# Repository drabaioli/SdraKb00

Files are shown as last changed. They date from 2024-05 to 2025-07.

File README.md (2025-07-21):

# SdraKb00

12 keys hot-swap macropad with rotary encoder.

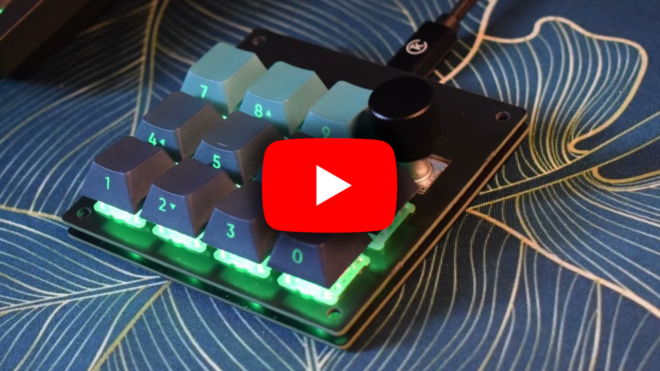
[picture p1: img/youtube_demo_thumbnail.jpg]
Watch the video (https://www.youtube.com/watch?v=uPEhIp7Z-5M)


## Assembled images

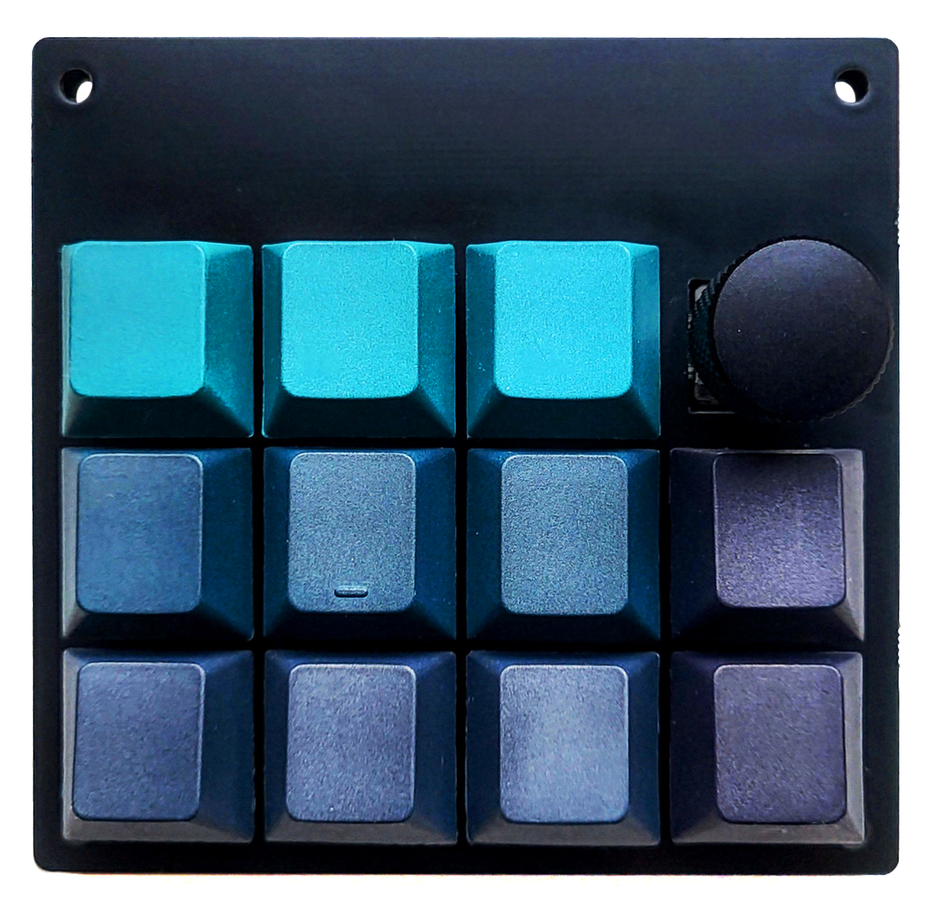
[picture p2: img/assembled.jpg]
assembled

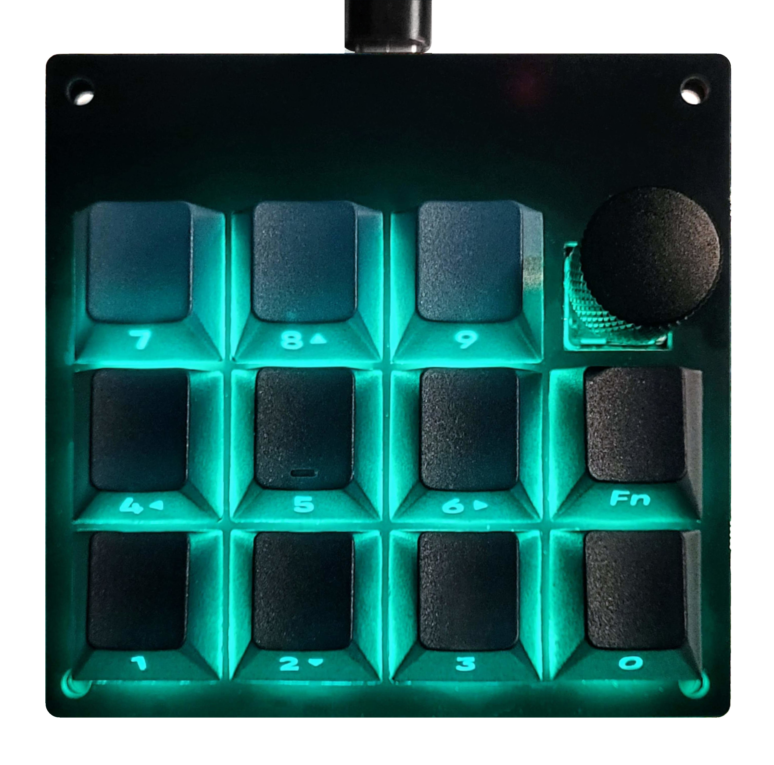
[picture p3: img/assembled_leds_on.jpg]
assembled_leds_on


## Features

- 11 hot-swap keys
- Rotary encoder with push button
- AtMega32U4 MCU
- Per-key RGB led for backlighting
- USB-C connector
- On PCB SPI header
- MCU reset button
- Switch mounting plate
- Power LED indicator

## Keyboard Layout Editor link

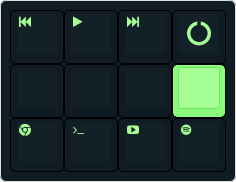
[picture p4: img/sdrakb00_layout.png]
layout
[](http://www.keyboard-layout-editor.com/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'fa%20fa-fast-backward'%3E%3C%2F%2Fi%3E&=%3Ci%20class%2F='fa%20fa-play'%3E%3C%2F%2Fi%3E&=%3Ci%20class%2F='fa%20fa-fast-forward'%3E%3C%2F%2Fi%3E&_a:7&f:9%3B&=%3Ci%20class%2F='fa%20fa-circle-o-notch'%3E%3C%2F%2Fi%3E%3B&@_f:3%3B&=&=&=&_c=%2388FB7A&t=%23101C24%3B&=%3B&@_c=%23101C24&t=%2388FB7A&a:4%3B&=%3Ci%20class%2F='fa%20fa-chrome'%3E%3C%2F%2Fi%3E&=%3Ci%20class%2F='fa%20fa-terminal'%3E%3C%2F%2Fi%3E&=%3Ci%20class%2F='fa%20fa-youtube-play'%3E%3C%2F%2Fi%3E&=%3Ci%20class%2F='fa%20fa-spotify'%3E%3C%2F%2Fi%3E)

## Schematic

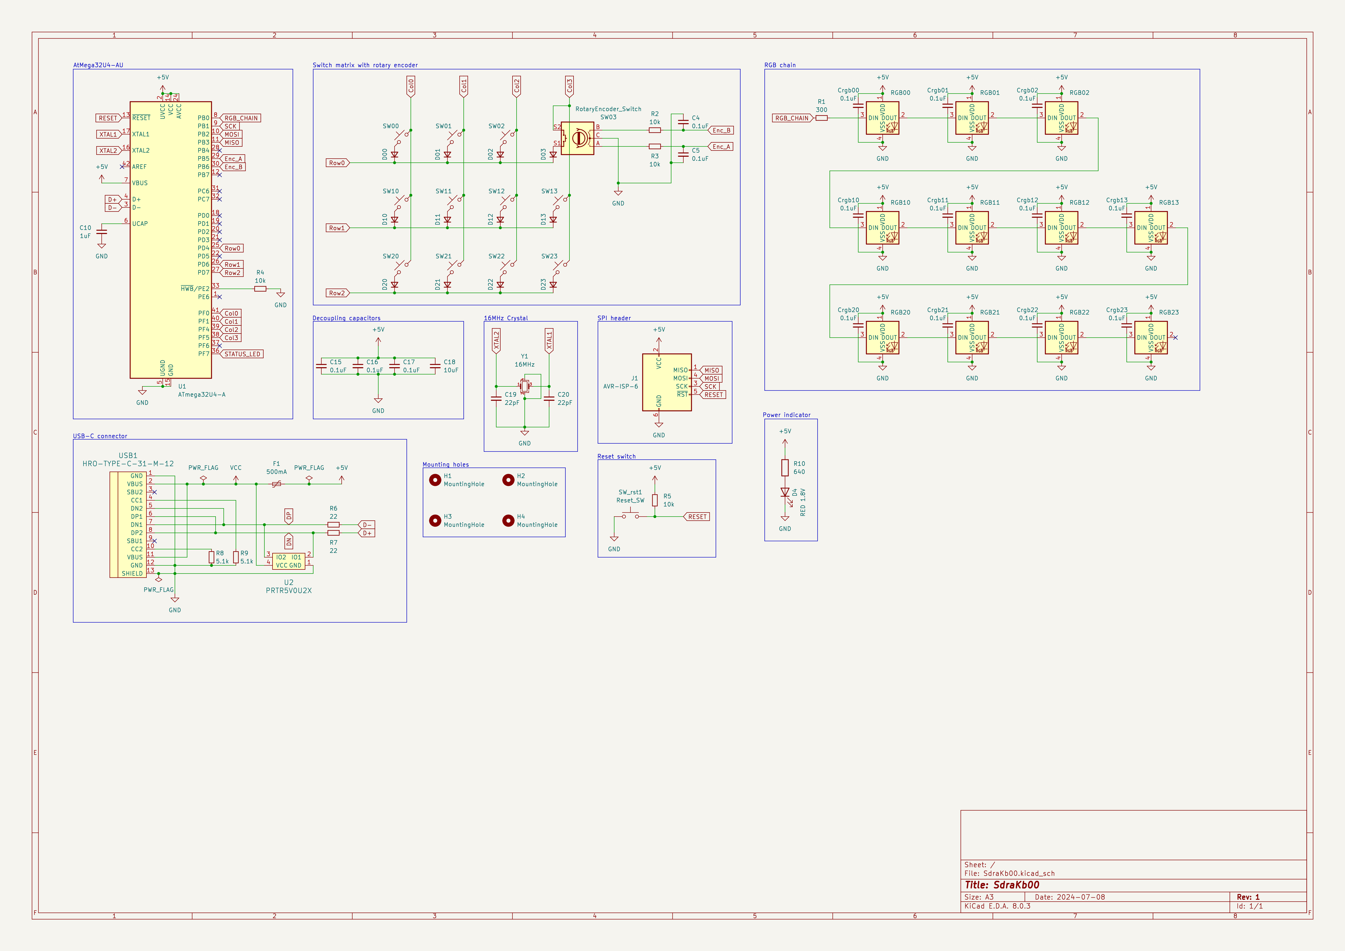
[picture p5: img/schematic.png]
schematic

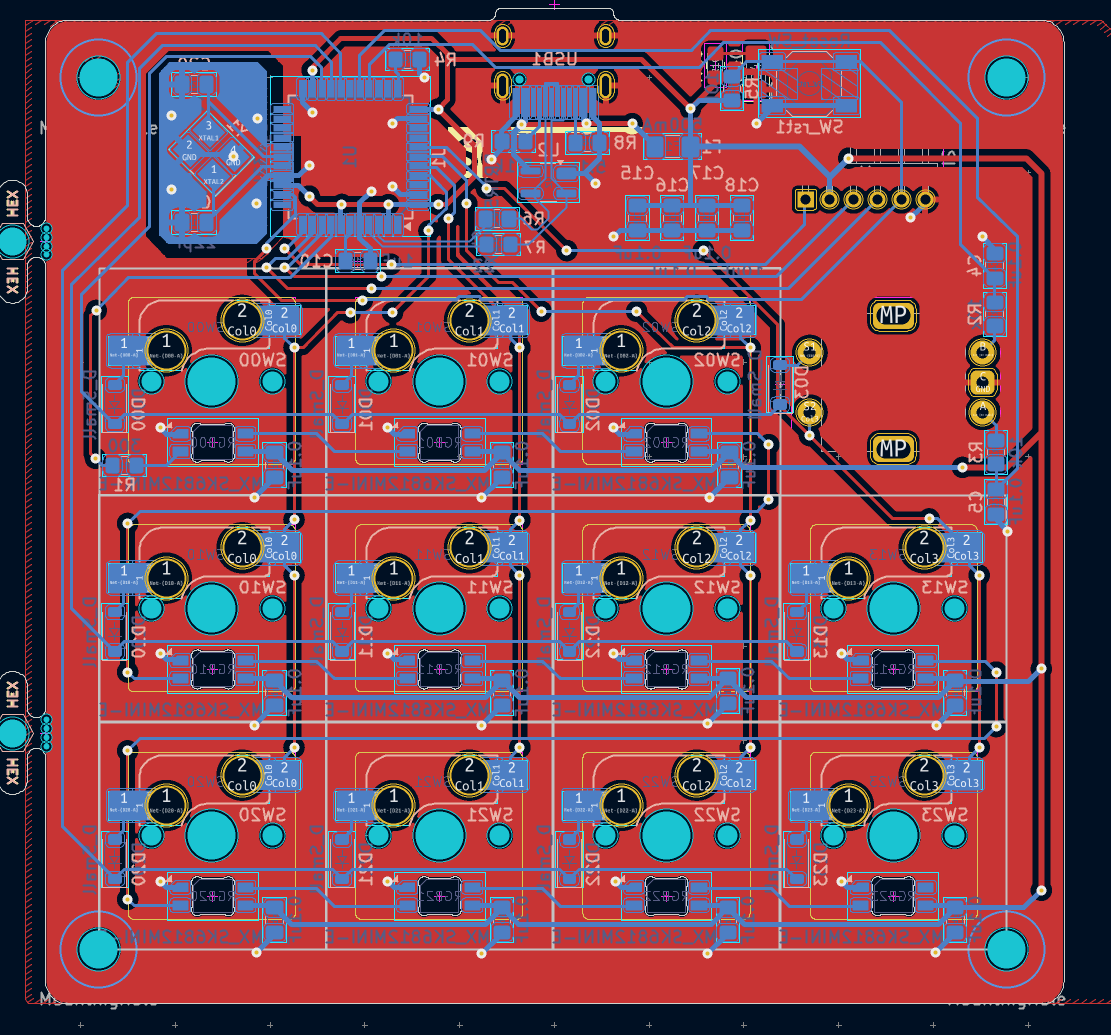
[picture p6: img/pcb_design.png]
pcb_design


## PCB

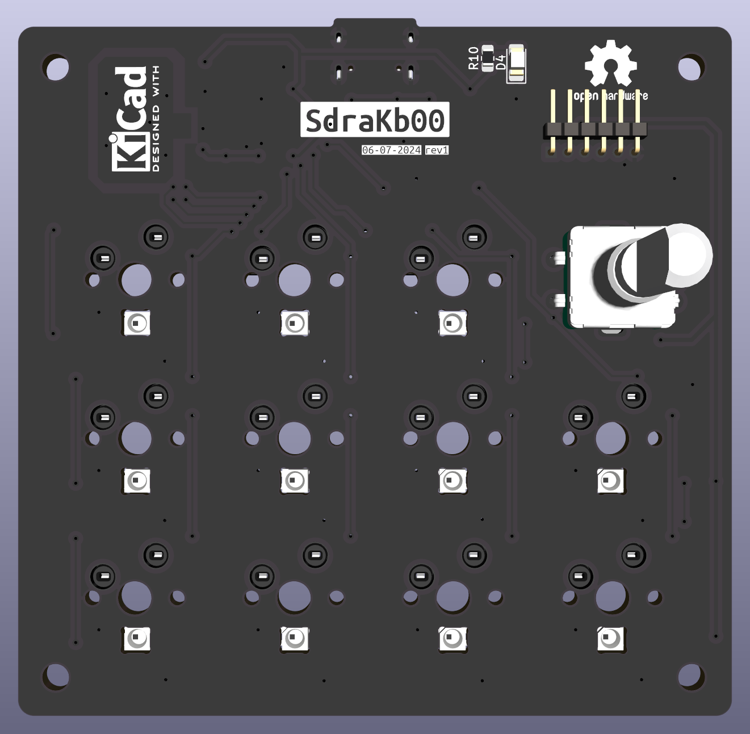
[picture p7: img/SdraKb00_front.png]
pcb_front

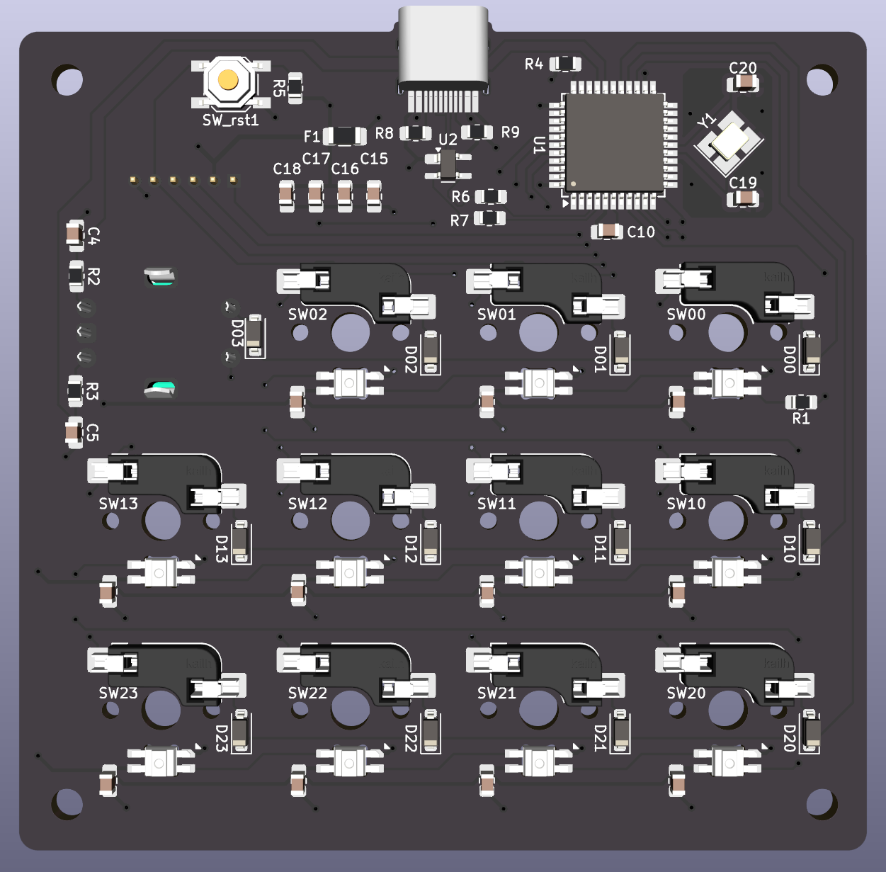
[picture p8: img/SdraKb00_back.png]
pcb_back


## Switch plate

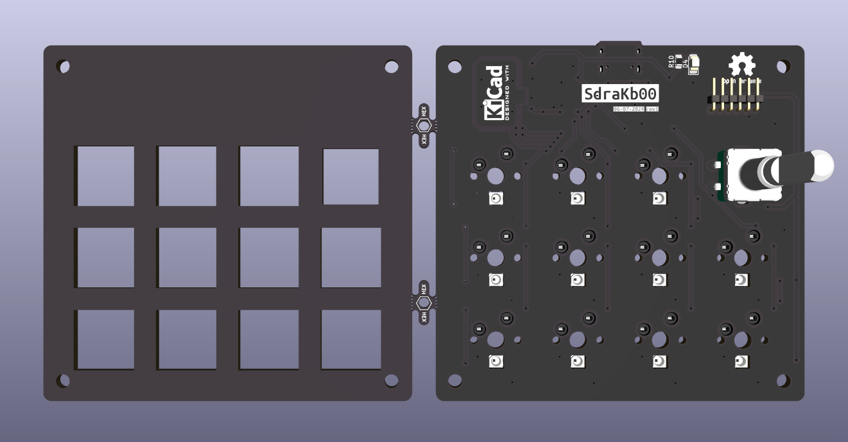
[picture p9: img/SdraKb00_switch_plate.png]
switch_plate


## Production files

The [production/](production/) folder contains files required for manufacturing the board, namely the [SdraKb00.zip](production/SdraKb00.zip) is an export (JLCPCB accepted format) of the gerber files and the [BOM](production/SdraKb00_bom.csv). The BOM was edited to add links to JLCPCB parts. Both files can be used to get the PCB manufactured by [JLCPCB](https://jlcpcb.com/) with relative components.

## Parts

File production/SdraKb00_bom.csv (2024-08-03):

Id | Designator | Footprint | Quantity | Designation | Supplier and ref | Comment | LCSC link
1 | R10 | R_0805_2012Metric_Pad1.20x1.40mm_HandSolder | 1 | 150 | C410057 |  | https://www.lcsc.com/product-detail/Chip-Resistor-Surface-Mount_PANASONIC-ERJ6GEYJ151V_C410057.html
2 | SW03 | ROT_Alps_EC11E-Switch | 1 | RotaryEncoder_Switch | C470742 |  | https://www.lcsc.com/product-detail/Rotary-Encoders_ALPSALPINE-EC11E09244BS_C470742.html
3 | D4 | LED_1206_3216Metric_Pad1.42x1.75mm_HandSolder | 1 | RED 2V | C125086 |  | https://www.lcsc.com/product-detail/span-style-background-color-ff0-LED-span-Indication-Discrete_Lite-On-LTST-C150KRKT_C125086.html
4 | J1 | PinHeader_1x06_P2.00mm_Horizontal | 1 | AVR-ISP-6 | C707009 |  | https://www.lcsc.com/product-detail/span-style-background-color-ff0-Pin-span-Headers_XKB-Connection-X4611WR-06I-C40D28_C707009.html
5 | D20,D12,D01,D22,D03,D10,D02,D23,D21,D13,D00,D11 | D_SOD-123 | 12 | D_Small | C77978 |  | https://www.lcsc.com/product-detail/Switching-Diodes_MCC-Micro-Commercial-Components-1N4148W-TP_C77978.html
5 | SW22,SW01,SW01,SW01,SW01,SW01,SW01,SW12,SW11,SW01,SW13,SW01,SW20,SW23,SW01,SW01,SW01,SW10,SW01,SW02,SW21,SW00 | SW_MX_HS_CPG151101S11_1u | 11 | SW_Push_45deg | C2803348 |  | https://www.lcsc.com/product-detail/Mechanical-Keyboard-Shaft_Kailh-CPG151101S11_C2803348.html
7 | RGB22,RGB01,RGB21,RGB00,RGB11,RGB20,RGB10,RGB13,RGB02,RGB12,RGB23 | LED_MX_6028R-ROT | 11 | MX_SK6812MINI-E | C5149201 |  | https://www.lcsc.com/product-detail/RGB-LEDs-Built-in-IC_OPSCO-Optoelectronics-SK6812MINI-E_C5149201.html
8 | Crgb23,C15,Crgb11,Crgb21,C4,Crgb00,Crgb13,Crgb22,C5,Crgb12,Crgb10,Crgb20,Crgb02,C17,Crgb01,C16 | C_0805_2012Metric_Pad1.18x1.45mm_HandSolder | 16 | 0.1uF | C730460 |  | https://www.lcsc.com/product-detail/Multilayer-Ceramic-Capacitors-MLCC-SMD-SMT_Samsung-Electro-Mechanics-CL21B104MBFNNNE_C730460.html
9 | C20,C19 | C_0805_2012Metric_Pad1.18x1.45mm_HandSolder | 2 | 22pF | C472837 |  | https://www.lcsc.com/product-detail/Multilayer-Ceramic-Capacitors-MLCC-SMD-SMT_Samsung-Electro-Mechanics-CL21C220JB61PNC_C472837.html
10 | R6,R7 | R_0805_2012Metric_Pad1.20x1.40mm_HandSolder | 2 | 22 | C413152 |  | https://www.lcsc.com/product-detail/Chip-Resistor-Surface-Mount_PANASONIC-ERJ6GEYJ220V_C413152.html
11 | F1 | Fuse_1206_3216Metric_Pad1.42x1.75mm_HandSolder | 1 | 500mA | C883126 |  | https://www.lcsc.com/product-detail/Resettable-Fuses_BHFUSE-BSMD1206-050-30V_C883126.html
12 | R8,R9 | R_0805_2012Metric_Pad1.20x1.40mm_HandSolder | 2 | 5.1k | C230649 |  | https://www.lcsc.com/product-detail/Chip-Resistor-Surface-Mount_PANASONIC-ERJ6GEYJ512V_C230649.html
13 | R5,R4,R2,R3 | R_0805_2012Metric_Pad1.20x1.40mm_HandSolder | 4 | 10k | C180849 |  | https://www.lcsc.com/product-detail/Chip-Resistor-Surface-Mount_PANASONIC-ERJ6GEYJ103V_C180849.html
14 | C10 | C_0805_2012Metric_Pad1.18x1.45mm_HandSolder | 1 | 1uF | C2798196 |  | https://www.lcsc.com/product-detail/Multilayer-Ceramic-Capacitors-MLCC-SMD-SMT_Samsung-Electro-Mechanics-CL21B105MBFNNNE_C2798196.html
15 | Y1 | Crystal_SMD_3225-4Pin_3.2x2.5mm_HandSoldering | 1 | 16MHz | C5380579 |  | https://www.lcsc.com/product-detail/Crystals_JGHC-S3216000222080C3_C5380579.html
16 | C18 | C_0805_2012Metric_Pad1.18x1.45mm_HandSolder | 1 | 10uF | C95841 |  | https://www.lcsc.com/product-detail/Multilayer-Ceramic-Capacitors-MLCC-SMD-SMT_Samsung-Electro-Mechanics-CL21B106KOQNNNE_C95841.html
17 | SW_rst1 | SW_SPST_SKQG_WithStem | 1 | Reset_SW | C116647 |  | https://www.lcsc.com/product-detail/Tactile-Switches_ALPSALPINE-SKQGADE010_C116647.html
18 | R1 | R_0805_2012Metric_Pad1.20x1.40mm_HandSolder | 1 | 300 | C413174 |  | https://www.lcsc.com/product-detail/Chip-Resistor-Surface-Mount_PANASONIC-ERJ6GEYJ301V_C413174.html
19 | U1 | TQFP-44_10x10mm_P0.8mm | 1 | ATmega32U4-A | C44854 |  | https://www.lcsc.com/product-detail/Microcontrollers-MCU-MPU-SOC_Microchip-Tech-ATMEGA32U4-AU_C44854.html
20 | USB1 | HRO-TYPE-C-31-M-12-HandSoldering | 1 | HRO-TYPE-C-31-M-12 | C165948 |  | https://www.lcsc.com/product-detail/USB-Type-C_Korean-Hroparts-Elec-TYPE-C-31-M-12_C165948.html
21 | U2 | SOT-143_Handsoldering | 1 | PRTR5V0U2X | C5375321 |  | https://www.lcsc.com/product-detail/ESD-and-Surge-Protection-TVS-ESD_Slkor-SLKORMICRO-Elec-PRTR5V0U2X_C5375321.html

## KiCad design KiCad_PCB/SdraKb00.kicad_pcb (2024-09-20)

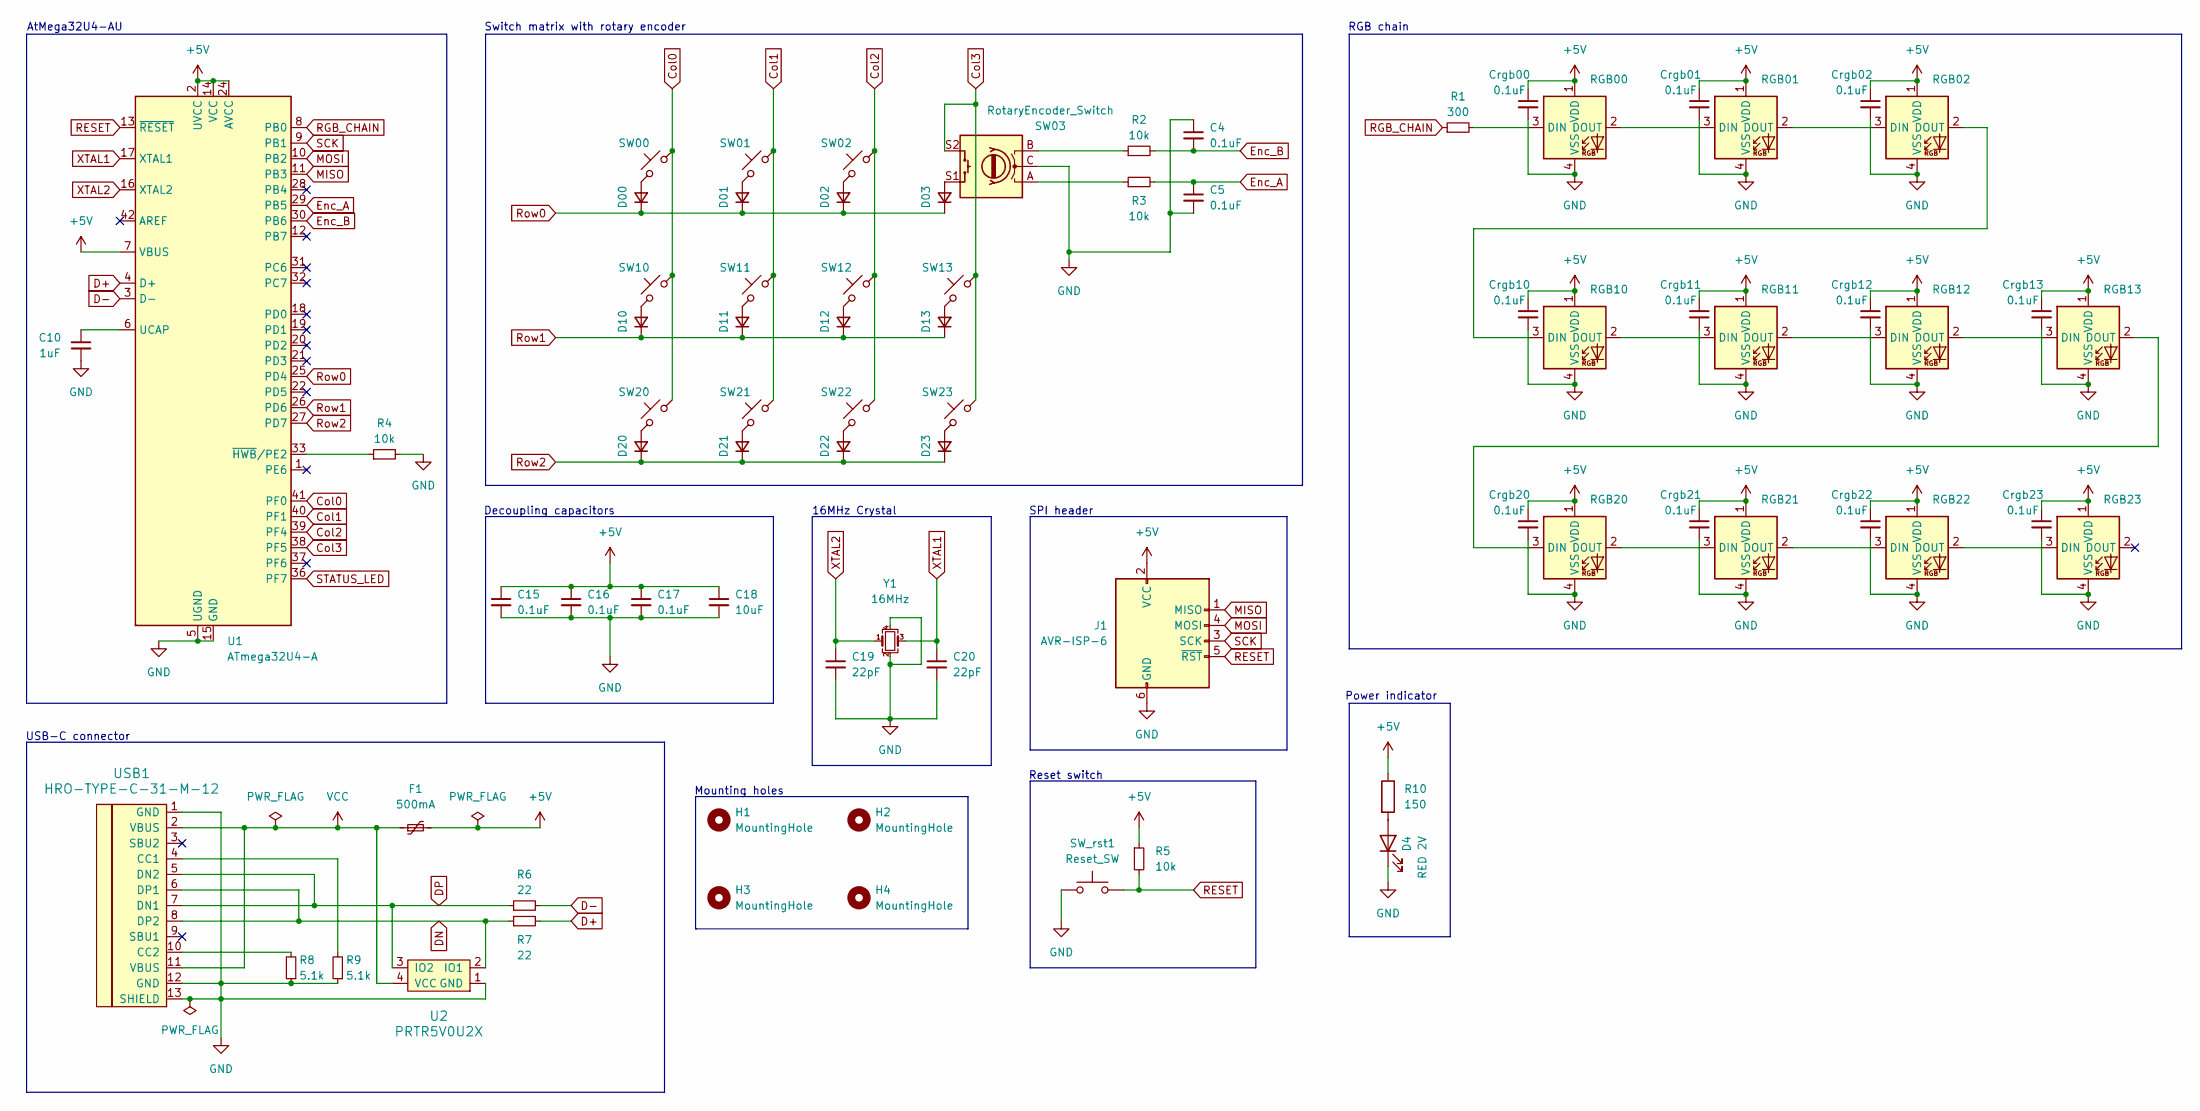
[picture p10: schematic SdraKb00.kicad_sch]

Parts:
C4, C5, C15, C16, C17: 0.1uF; C_0805_2012Metric_Pad1.18x1.45mm_HandSolder
C10: 1uF; C_0805_2012Metric_Pad1.18x1.45mm_HandSolder
C18: 10uF; C_0805_2012Metric_Pad1.18x1.45mm_HandSolder
C19, C20: 22pF; C_0805_2012Metric_Pad1.18x1.45mm_HandSolder
Crgb00, Crgb01, Crgb02, Crgb10, Crgb11, Crgb12, Crgb13, Crgb20, Crgb21, Crgb22, Crgb23: 0.1uF; C_0805_2012Metric_Pad1.18x1.45mm_HandSolder
D00, D01, D02, D03, D10, D11, D12, D13, D20, D21, D22, D23: D_Small; D_SOD-123
D4: RED 2V; LED_1206_3216Metric_Pad1.42x1.75mm_HandSolder
F1: 500mA; Fuse_1206_3216Metric_Pad1.42x1.75mm_HandSolder
H1, H2, H3, H4: MountingHole; MountingHole_3.2mm_M3
J1: AVR-ISP-6; PinHeader_1x06_P2.00mm_Horizontal
R1: 300; R_0805_2012Metric_Pad1.20x1.40mm_HandSolder
R2, R3, R4, R5: 10k; R_0805_2012Metric_Pad1.20x1.40mm_HandSolder
R6, R7: 22; R_0805_2012Metric_Pad1.20x1.40mm_HandSolder
R8, R9: 5.1k; R_0805_2012Metric_Pad1.20x1.40mm_HandSolder
R10: 150; R_0805_2012Metric_Pad1.20x1.40mm_HandSolder
RGB00, RGB01, RGB02, RGB10, RGB11, RGB12, RGB13, RGB20, RGB21, RGB22, RGB23: MX_SK6812MINI-E; LED_MX_6028R-ROT
SW00, SW01, SW02, SW10, SW11, SW12, SW13, SW20, SW21, SW22, SW23: SW_Push_45deg; SW_MX_HS_CPG151101S11_1u
SW03: RotaryEncoder_Switch; ROT_Alps_EC11E-Switch
SW_rst1: Reset_SW; SW_SPST_SKQG_WithStem
U1: ATmega32U4-A; TQFP-44_10x10mm_P0.8mm
U2: PRTR5V0U2X; SOT-143_Handsoldering
USB1: HRO-TYPE-C-31-M-12; HRO-TYPE-C-31-M-12-HandSoldering
Y1: 16MHz; Crystal_SMD_3225-4Pin_3.2x2.5mm_HandSoldering

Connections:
+5V: C15.1, C16.1, C17.1, C18.1, Crgb00.1, Crgb01.1, Crgb02.1, Crgb10.1, Crgb11.1, Crgb12.1, Crgb13.1, Crgb20.1, Crgb21.1, Crgb22.1, Crgb23.1, F1.2, J1.2 (VCC), R5.1, R10.1, RGB00.1 (VDD), RGB01.1 (VDD), RGB02.1 (VDD), RGB10.1 (VDD), RGB11.1 (VDD), RGB12.1 (VDD), RGB13.1 (VDD), RGB20.1 (VDD), RGB21.1 (VDD), RGB22.1 (VDD), RGB23.1 (VDD), U1.2 (UVCC), U1.7 (VBUS), U1.14 (VCC), U1.24 (AVCC), U1.34 (VCC), U1.44 (AVCC)
Col0: SW00.2, SW10.2, SW20.2, U1.41 (PF0)
Col1: SW01.2, SW11.2, SW21.2, U1.40 (PF1)
Col2: SW02.2, SW12.2, SW22.2, U1.39 (PF4)
Col3: SW03.S2, SW13.2, SW23.2, U1.38 (PF5)
D+: R7.2, U1.4 (D+)
D-: R6.2, U1.3 (D-)
DN: R7.1, U2.2 (IO1), USB1.6 (DP1), USB1.8 (DP2)
DP: R6.1, U2.3 (IO2), USB1.5 (DN2), USB1.7 (DN1)
Enc_A: C5.1, R3.2, U1.29 (PB5)
Enc_B: C4.2, R2.2, U1.30 (PB6)
GND: C4.1, C5.2, C10.2, C15.2, C16.2, C17.2, C18.2, C19.2, C20.2, Crgb00.2, Crgb01.2, Crgb02.2, Crgb10.2, Crgb11.2, Crgb12.2, Crgb13.2, Crgb20.2, Crgb21.2, Crgb22.2, Crgb23.2, D4.1 (K), J1.6 (GND), R4.2, R8.1, R9.1, RGB00.4 (VSS), RGB01.4 (VSS), RGB02.4 (VSS), RGB10.4 (VSS), RGB11.4 (VSS), RGB12.4 (VSS), RGB13.4 (VSS), RGB20.4 (VSS), RGB21.4 (VSS), RGB22.4 (VSS), RGB23.4 (VSS), SW03.C, SW_rst1.1, U1.5 (UGND), U1.15 (GND), U1.23 (GND), U1.35 (GND), U1.43 (GND), U2.1 (GND), USB1.1 (GND), USB1.12 (GND), USB1.13 (SHIELD), Y1.2, Y1.4
MISO: J1.1 (MISO), U1.11 (PB3)
MOSI: J1.4 (MOSI), U1.10 (PB2)
unnamed: D00.2 (A), SW00.1
unnamed: D01.2 (A), SW01.1
unnamed: D02.2 (A), SW02.1
unnamed: D03.2 (A), SW03.S1
unnamed: D4.2 (A), R10.2
unnamed: D10.2 (A), SW10.1
unnamed: D11.2 (A), SW11.1
unnamed: D12.2 (A), SW12.1
unnamed: D13.2 (A), SW13.1
unnamed: D20.2 (A), SW20.1
unnamed: D21.2 (A), SW21.1
unnamed: D22.2 (A), SW22.1
unnamed: D23.2 (A), SW23.1
unnamed: R2.1, SW03.B
unnamed: R3.1, SW03.A
unnamed: R1.2, RGB00.3 (DIN)
unnamed: RGB00.2 (DOUT), RGB01.3 (DIN)
unnamed: RGB01.2 (DOUT), RGB02.3 (DIN)
unnamed: RGB02.2 (DOUT), RGB10.3 (DIN)
unnamed: RGB10.2 (DOUT), RGB11.3 (DIN)
unnamed: RGB11.2 (DOUT), RGB12.3 (DIN)
unnamed: RGB12.2 (DOUT), RGB13.3 (DIN)
unnamed: RGB13.2 (DOUT), RGB20.3 (DIN)
unnamed: RGB20.2 (DOUT), RGB21.3 (DIN)
unnamed: RGB21.2 (DOUT), RGB22.3 (DIN)
unnamed: RGB22.2 (DOUT), RGB23.3 (DIN)
unnamed: C10.1, U1.6 (UCAP)
unnamed: R4.1, U1.33 (~HWB/PE2)
unnamed: R9.2, USB1.4 (CC1)
unnamed: R8.2, USB1.10 (CC2)
RESET: J1.5 (~RST), R5.2, SW_rst1.2, U1.13 (~RESET)
RGB_CHAIN: R1.1, U1.8 (PB0)
Row0: D00.1 (K), D01.1 (K), D02.1 (K), D03.1 (K), U1.25 (PD4)
Row1: D10.1 (K), D11.1 (K), D12.1 (K), D13.1 (K), U1.26 (PD6)
Row2: D20.1 (K), D21.1 (K), D22.1 (K), D23.1 (K), U1.27 (PD7)
SCK: J1.3 (SCK), U1.9 (PB1)
STATUS_LED: U1.36 (PF7)
VCC: F1.1, U2.4 (VCC), USB1.2 (VBUS), USB1.11 (VBUS)
XTAL1: C20.1, U1.17 (XTAL1), Y1.3
XTAL2: C19.1, U1.16 (XTAL2), Y1.1

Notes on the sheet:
USB-C connector
RGB chain
Reset switch
Mounting holes
Power indicator
SPI header
AtMega32U4-AU
Switch matrix with rotary encoder
16MHz Crystal
Decoupling capacitors

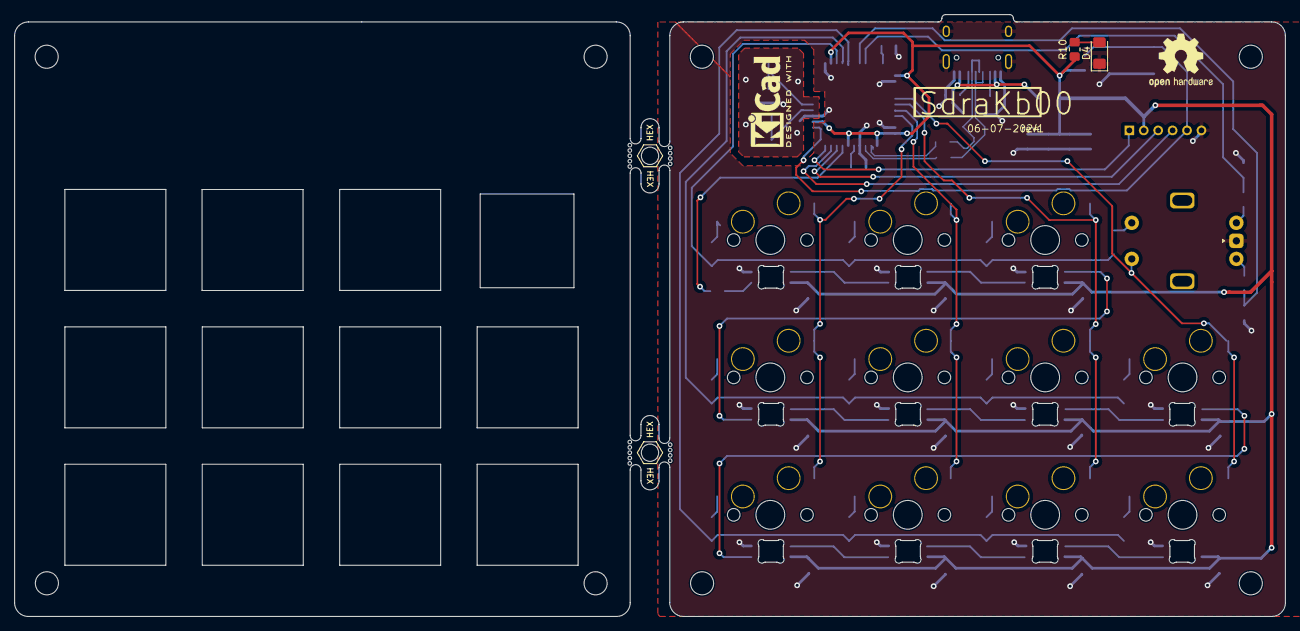
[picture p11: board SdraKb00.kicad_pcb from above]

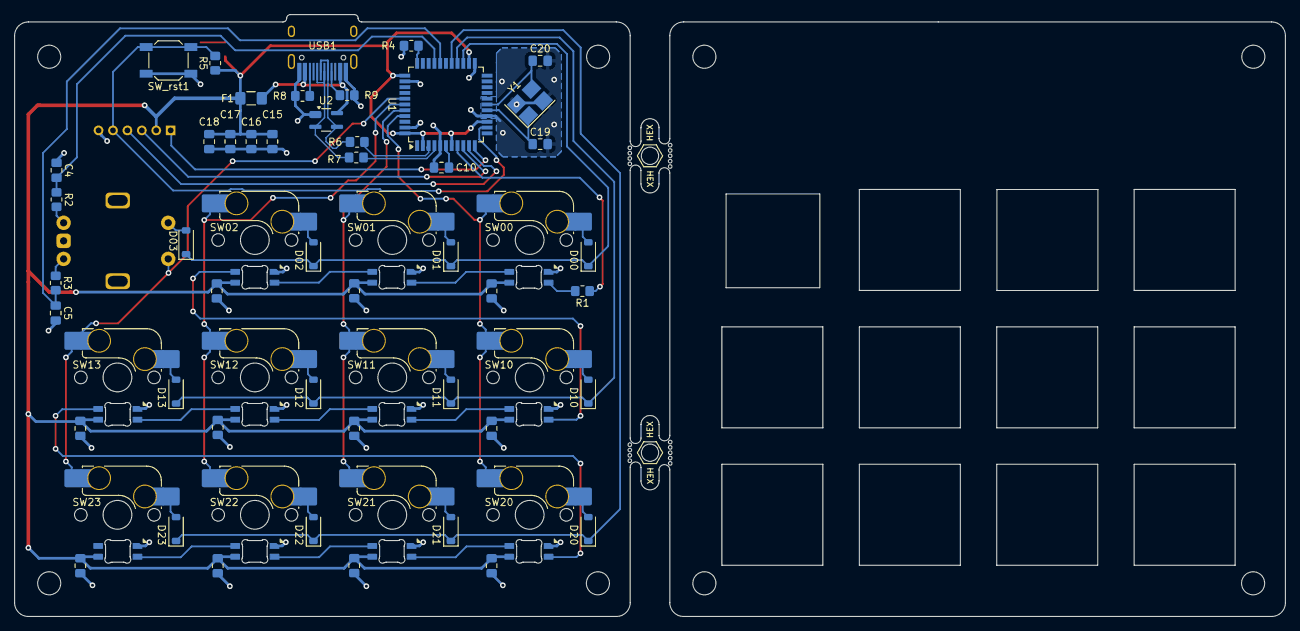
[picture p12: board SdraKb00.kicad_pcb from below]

Board: 2 copper layers, 176.2 x 83.4 mm, 95 parts (80 on the bottom side), 53 nets.

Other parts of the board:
H5, H6, H7, H8: MountingHole; MountingHole_3.2mm_M3
MB5, MB5#2: 5.5mm; mousebites_5p5mm_easysnap
SW00_cutout, SW01_cutout, SW02_cutout, SW10_cutout, SW11_cutout, SW12_cutout, SW13_cutout, SW20_cutout, SW21_cutout, SW22_cutout, SW23_cutout: SW_Push_45deg; SW_MX_HS_CPG151101S11_1u
SW03_cutout: RotaryEncoder_Switch; ROT_Alps_EC11E-Switch

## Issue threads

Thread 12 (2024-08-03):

Create components for switch mounting plate

drabaioli, 2024-08-03:
The mounting plate was created by copy/pasting the main PCB and removing all parts not required. This duplicates the number of components used to build the board (which messes up the BOM). Delete duplicated components and replace them with a dedicated component (by creating a new footprint).

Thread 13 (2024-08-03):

JLC feedback: "There are too many small slots in your file , it will take too much time to get it finished during the routing process."

drabaioli, 2024-08-03:
Not an expert but I think this means that the size for the CNC milling was too small

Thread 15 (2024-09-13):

"Status LED" on pin 36 was neger added to the PCB

drabaioli, 2024-09-13:
Either remove it from the schematic, or even better add it to the PCB, since this can be used for debugging purposes.

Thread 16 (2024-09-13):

ISP ping are not of the right size

drabaioli, 2024-09-13:
ISP pins are too small for the pin connectors I have (used for prototiping on breadboards). Either use bigger 6P pins, or leave the holes in the PCB and don't solder a 6P pinset (just solder some wires).

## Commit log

2024-05-10 Ignoring KiCad tmp files. (#1)
2024-05-12 Repo setup (#2)
    * Setup project and submodules.
    * Initial sketch based on jeremypaton (see link below)
    https://www.jeremypaton.com/2021/04/20/designing-a-custom-keyboard-pt-1/
    * Fixing library paths.
    * Adjusted first sketch based on masterzen.
    https://www.masterzen.fr/2020/05/03/designing-a-keyboard-part-1/
    * Adding layout image to readme.
    * Replaced AtMega32U4 with default library. Adding switch array.
    * Adding RGB chain.
    * Adding mounting holes.
    * Readme.
    [SdraKb00.kicad_pcb, SdraKb00.kicad_sch]
2024-05-19 Assign footprints (#3)
    * First round assigning footprints.
    * Complete footprint assignment.
    - Removed unused submodules
    - Adding marbastlib submodule
    [SdraKb00.kicad_sch]
2024-07-05 Pcb design (#4)
    * Aligning SWs, Ds, LEDs.
    * Placing all components before routing.
    * More wiring.
    * More PCB routing.
    * Routing MCU powerlines, Crystal ground zone.
    * Finish routing power.
    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
    [SdraKb00.kicad_pcb, SdraKb00.kicad_sch]
2024-07-06 Silkscreen (#5)
    * Adding initial silkscreen.
    * Adding KiCad & OpenHW logos.
    [SdraKb00.kicad_pcb]
2024-07-06 Adding PCB renders. (#6)
    [SdraKb00.kicad_pcb]
2024-07-10 Adding power indicator LED (#7)
    * Adding power indicator LED.
    * Re-placing silkscreen.
    [SdraKb00.kicad_pcb, SdraKb00.kicad_sch]
2024-07-20 Mounting plate (#8)
    * Adding switch mounting plate.
    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
    [SdraKb00.kicad_pcb]
2024-07-21 Adding 3D model for reset button (#9)
    * Adding 3D model for reset button.
    * Adding back render.
    [SdraKb00.kicad_pcb]
2024-07-26 Changing power indicator specs. (#10)
    [SdraKb00.kicad_pcb, SdraKb00.kicad_sch]
2024-08-03 Production files (#11)
    * Adding gerber files and BOM.
    * Adding (ignored) bom.
    [SdraKb00_bom.csv]
2024-09-20 Adding assembled result images. (#17)
    [SdraKb00.kicad_pcb]
